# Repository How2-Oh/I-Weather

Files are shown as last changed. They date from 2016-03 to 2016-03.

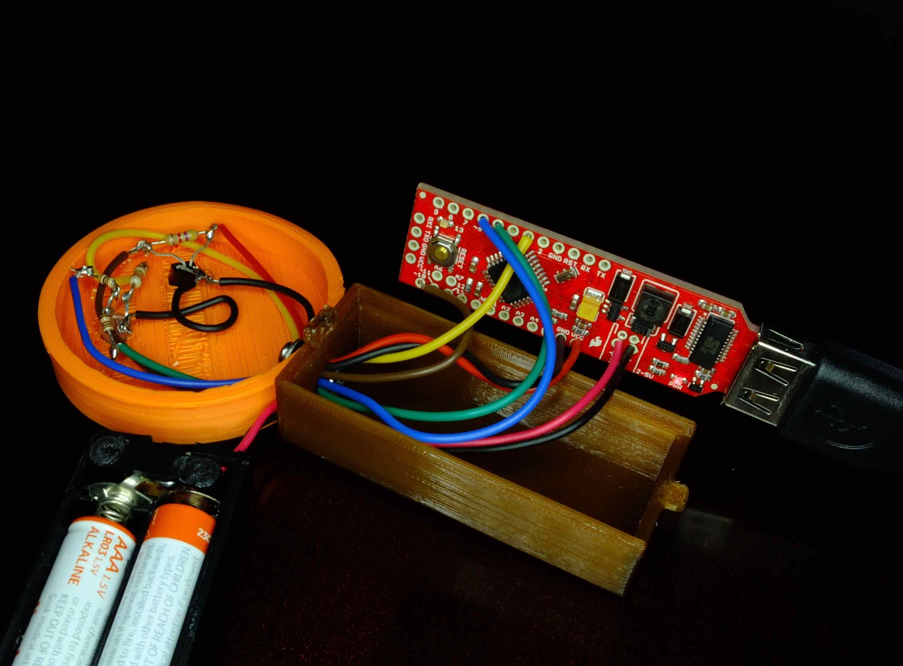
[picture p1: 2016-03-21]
Photos/Complete_Test.jpg

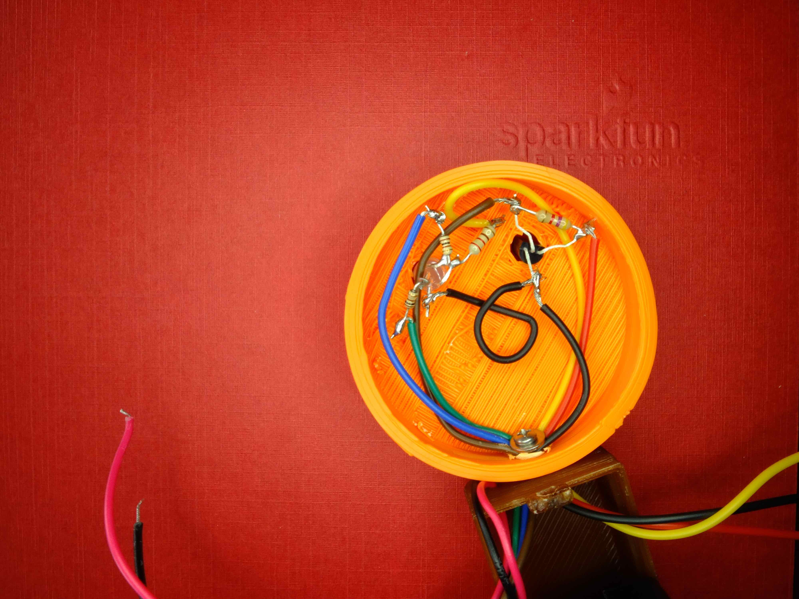
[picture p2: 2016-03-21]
Photos/Button_Wiring.jpg

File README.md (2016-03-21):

# I, Weather

Keep your "eye" on the weather. There are few areas in everyday life that suffer from data overload quite like the weather. All you want to know is, "what's it like outside right now?" Instead of a nice simple answer, you are deluged with more data points that you can sling a psychrometer at: dew points, inches of mercury (mercury!!), humidity, wind speed, and, of course, temperature. My kids don't want to know any of that "techie stuff," they just want to know is it "nice, hot, or cold" outside...right now.



Today with the SparkFun Electronics RedStick and a couple of discrete parts, you can answer that simple weather question with "I, Weather."

Securely installed inside a beautifully designed 3D-printed custom case (files available on Thingiverse), "I, Weather" provides you with a clear, easy-to-understand weather synopsis. Optimized Arduino code (files available on GitHub) featuring a WatchDog timer enables "I, Weather" to sip just enough juice from its dual AAA battery pack to keep your weather fix going and going.

Here's how it works: the RedStick is safely mounted inside the battery pack within a custom 3D-printed lid. The temperature sensor and RGB LED are neatly arranged inside a 3D-printed button disc. Two "eye" openings in the button enable the sensor to reliably read the ambient air temperature and the LED to "wink" the current temperature. A back is glued (use Testors Cement for Plastic Models No. 3512) on the button for protecting the internal wiring from dust and debris.

When the power switch is turned ON, "I, Weather" performs a startup test of the RGB LED, pulsing red, green, and blue. Upon completion of this test, the WatchDog timer kicks in and puts the RedStick to "sleep" for approximately 5 minutes. After the 5 minute interval, "I, Weather" wakes up, grabs a quick temperature reading, and pulses the RGB LED twice with the appropriate color: green = "nice;" 68 - 78 degs F, red = "hot;" above 78 degs F, and blue = "cold;" below 68 degs F. [Hey, we live on the Gulf Coast; and below 68 degs F IS kinda cool.]

##Parts

* SparkFun RedStick #DEV-13741
* LED - RGB Diffused Common Cathode #COM-09264
* One Wire Digital Temperature Sensor DS18B20 #SEN-00245
* Battery Holder 2xAAA with Cover and Switch #PRT-09543
* 4.7K, 180-ohm (I used a 220-ohm), (2) 100-ohm Resistor Kit #COM-10969
* Hook-Up Wire - Assortment #PRT-11375
* 2-56 Machine Screw Fastener, two 2-56 Washers, one 2-56 Hex Nut #PRT-08993, #PRT-08995

##Step-by-Step

1. Download, read, and understand ALL of the datasheets, schematics, and tutorials from SparkFun Electronics for each of the parts.

2. Solder the 180-ohm (or, 220-ohm) resistor to pin 1 of the RGB LED.

3. Solder the two 100-ohm resistors to pins 3 and 4 of the LED.

4. Solder the 4.7K resistor between pins 2 and 3 of the DS18B20. The remaining steps are simple wiring connections.

5. Attach a yellow wire (avoid a red wire so that you'll minimize confusion with the red "power" wires used later in this project) to the 180-ohm resistor on pin 1, a green wire to the 100-ohm resistor on pin 3, a blue wire to the final 100-ohm resistor on pin 4, and a black wire to pin 2 of the LED.

6. Solder a brown wire (or, white wire) to pin 2, a red wire to pin 3, and a black wire to pin 1 of the DS18B20 sensor.

7. Connect the black wire from the LED (see Step 5) to pin 1 of the sensor.

8. The wiring harness is now complete.

9. Mould the wiring, resistors, sensor, and LED so that they all fit comfortably inside the button disc. The sensor should sit flush with the outside of one of the button's eye openings, while the LED should protrude through the other eye opening.

10. Snake all wiring through the opening in the base of the button and through a matching opening inside the battery lid.

11. Run the external red and black wires from the battery pack through the two wire openings in the battery lid.

12. Secure the button to the battery lid with the 2-56 hardware.

13. Solder ALL wire connections to the RedStick: yellow (from pin 1 of the LED) to pin 3, green to pin 5, blue to pin 6, brown (from pin 2 of the sensor) to pin 10, red from the sensor to pin VCC, black from the sensor to pin GND, red from the battery pack to +, and black from the battery pack to -.

14. Connect the RedStick to your PC and upload the IWeather.ino code. [NOTE: I used a USB port extender cable connecting the RedStick to the PC.]

15. Ensure "I, Weather" is performing its startup sequence and pulsing the correct temperature every five minutes before you disconnect the PC.

16. If everything checks out OK, remove the RedStick from the PC and insulate the bottom of the board with a piece of tape (i.e., so the metal batteries don't short circuit any of the board's connections).

17. Glue the back on the button and stuff all of the wiring and RedStick inside the battery lid. [NOTE: there's a slot in the lid for enabling the RedStick's USB "fingers" to stick out.]

18. Insert two AAA batteries, slide the battery lid closed, secure the battery pack with a piece of tape, and install "I, Weather" inside/outside away from direct sunlight and moisture.

##Bonus "Expert" Tips

The red Power Indicator LED is continually drawing precious amounts of power from the battery pack. Carefully study the RedStick schematic and remove this LED (D2) along with the 6.8K resistor (R2).

If your "I, Weather" is constantly "resetting" itself during or following assembly, the RedStick "reset" button (S1) might be the culprit. Again, carefully review the RedStick schematic and remove this button.

-end-

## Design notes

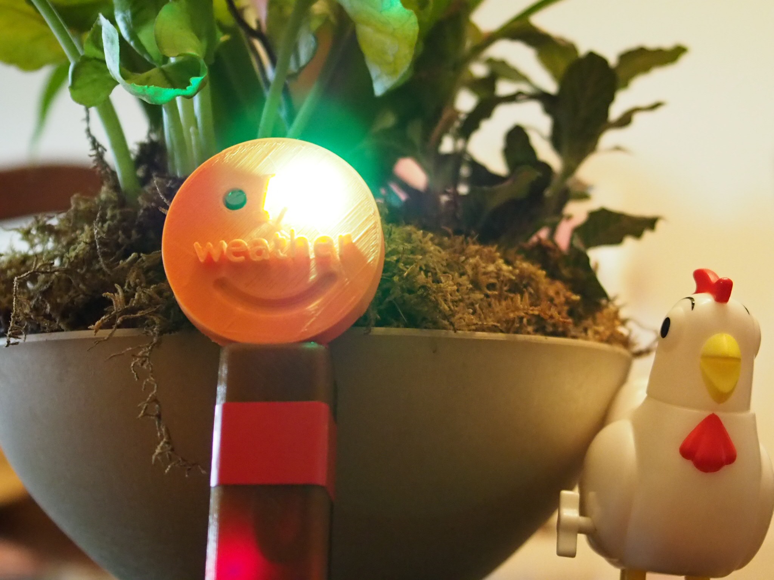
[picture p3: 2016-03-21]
Photos/Nice.JPG

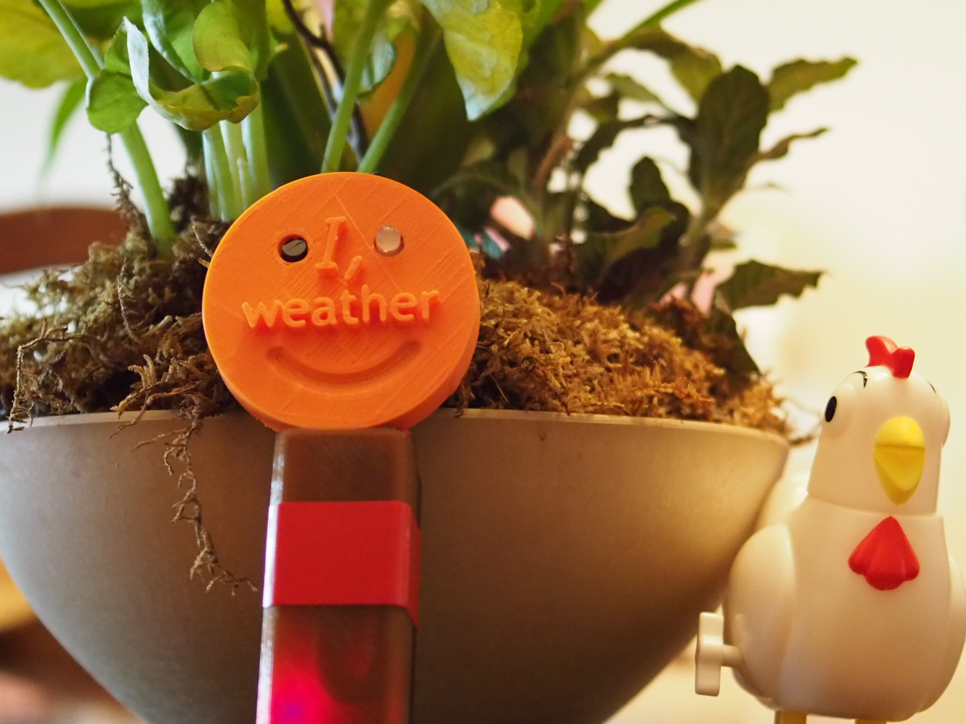
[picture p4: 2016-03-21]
Photos/IWeather.JPG

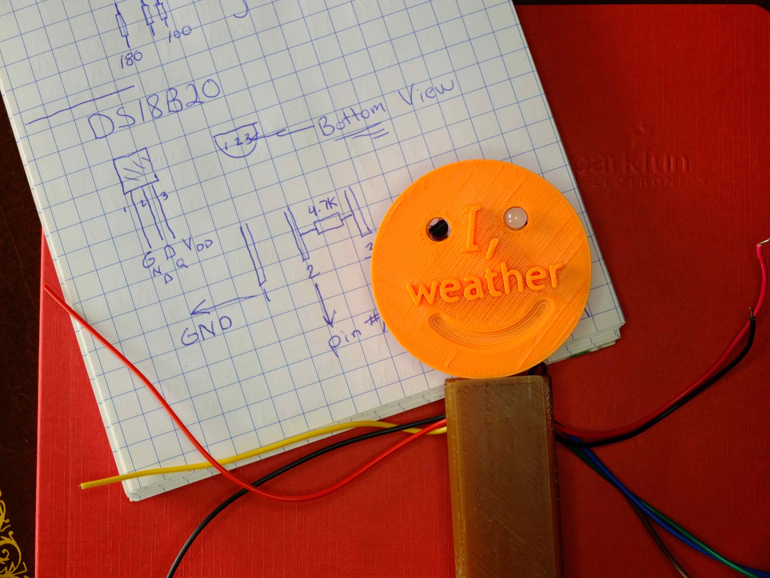
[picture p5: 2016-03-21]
Photos/Ready_4_RedStick.jpg

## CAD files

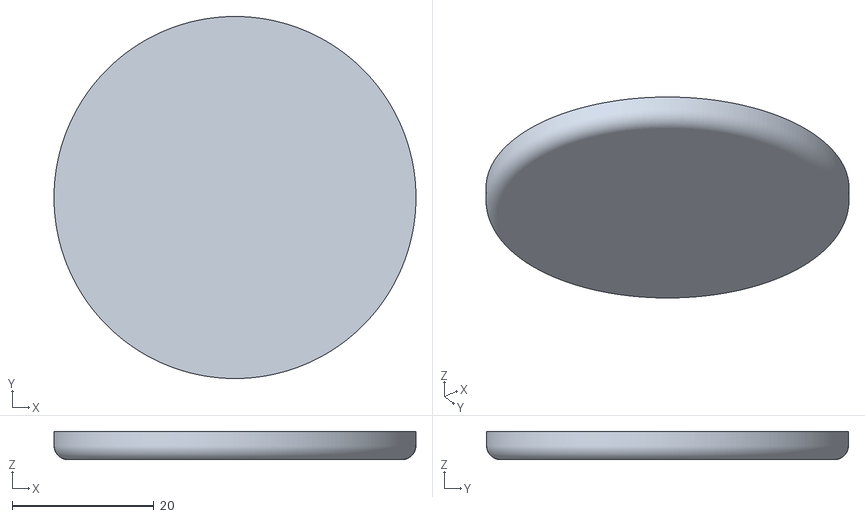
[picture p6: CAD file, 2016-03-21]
3DFiles/Weather_Back.stl
51.0 x 51.0 x 4.00

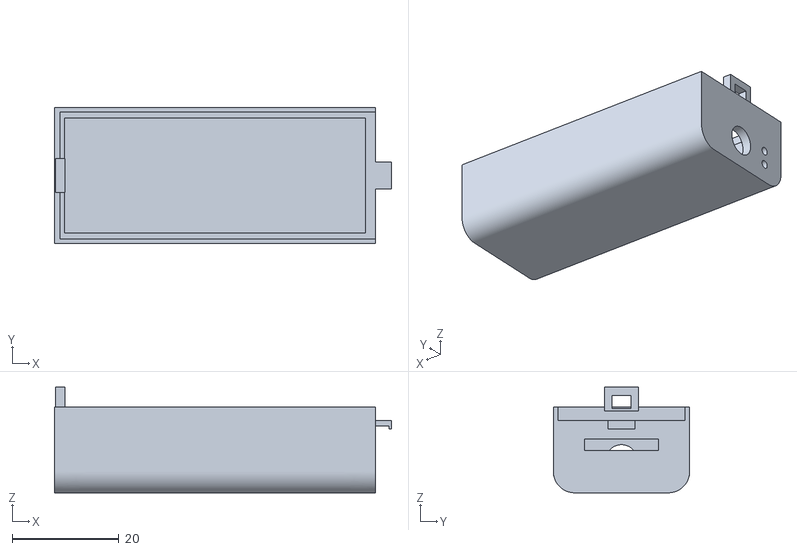
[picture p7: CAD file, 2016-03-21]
3DFiles/Battery_Lid.stl
63.0 x 25.5 x 19.8

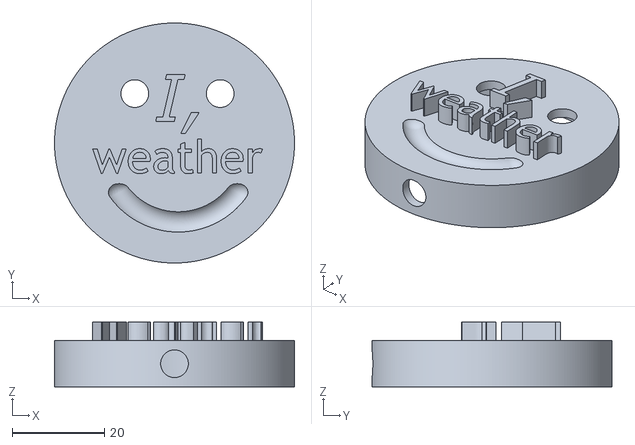
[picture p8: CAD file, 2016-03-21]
3DFiles/Weather_Button.stl
52.0 x 52.0 x 14.0

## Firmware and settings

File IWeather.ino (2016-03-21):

/* I, Weather
 *  A SparkFun Electronics RedStick Companion
 *  
 *  Based on the following libraries:
  * OneWire DS18B20 Thermometer
 *
 * RGB LED by BARRAGAN http://barraganstudio.com
 * 
 * The Watchdog & Sleep Mode code was lovingly adapted from
   Nathan Seidle's SparkFun Electronics Arduino code for
   H2OhNo!.


This sketch enables you to read a temperature from the  
connected DS18B20 and display the results on an PWM-
connected RGB LED.

RGB LED:
RedStick -------------------------------- RGB LED
3 -------------- 180-ohm resistor ------- 1 (Red)
5 -------------- 100-ohm resistor ------- 3 (Green)
6 -------------- 100-ohm resistor ------- 4 (Blue)
GND ------------------------------------- 2 (Common Cathode)

DS18B20:
RedStick --------------- DS18B20
VCC -------------------- VDD (pin #3)
10 --------------------- DQ (pin #2)
GND -------------------- GND (pin #1)
5V --- 4.7K resistor --- DQ (pin #2)

2xAAA Battery Pack:
RedStick ----------- Battery Pack
+ ------------------ Battery Red
- ------------------ Battery Black
*/

#include <OneWire.h>
#include <avr/sleep.h>

int i = 0; // An incremental timing variable for use during display

// Variables for the RGB LED
int RedPin = 3; //RED pin of the LED to PWM pin 3
int GreenPin = 5; // GREEN pin of the LED to PWM pin 5
int BluePin = 6; // BLUE pin of the LED to PWM pin 6
int brightness = 0; // LED brightness
int increment = 5; // brightness increment

// Our DS18B20 temperature variables
float celsius, fahrenheit;

OneWire  ds(10);  // Thermometer is on pin 10 (a 4.7K resistor is necessary)

volatile int watchdog_counter;

//This runs each time the watchdog wakes up
ISR(WDT_vect){
  watchdog_counter++;
}

void setup()
{

// Configure the RGB LED for OUTPUT
  pinMode(RedPin, OUTPUT);
  pinMode(GreenPin, OUTPUT);
  pinMode(BluePin, OUTPUT);

// Countdown to start R -> G -> B
  for (i=0; i<100; i++) {
    brightness = brightness + increment;  // increment brightness for next loop iteration
      if (brightness <= 0 || brightness >= 255)
        {
          increment = -increment;
        }
    brightness = constrain (brightness, 0, 255);
    analogWrite(RedPin, brightness);
// reverse the direction of the fading
    delay(20); // wait for 20 milliseconds to see the dimming effect
  }
  for (i=0; i<100; i++) {
    brightness = brightness + increment;  // increment brightness for next loop iteration
      if (brightness <= 0 || brightness >= 255)
        {
          increment = -increment;
        }
    brightness = constrain (brightness, 0, 255);
    analogWrite(GreenPin, brightness);
// reverse the direction of the fading
    delay(20); // wait for 20 milliseconds to see the dimming effect
  }
  for (i=0; i<100; i++) {
    brightness = brightness + increment;  // increment brightness for next loop iteration
      if (brightness <= 0 || brightness >= 255)
        {
          increment = -increment;
        }
    brightness = constrain (brightness, 0, 255);
    analogWrite(BluePin, brightness);
// reverse the direction of the fading
    delay(20); // wait for 20 milliseconds to see the dimming effect
  }
// Turn LED OFF
  brightness = 0;
  analogWrite(BluePin, brightness);
  analogWrite(RedPin, brightness);
  analogWrite(GreenPin, brightness);

// Our sleep code
watchdog_counter = 0;

//Power down all unnecessary hardware
set_sleep_mode(SLEEP_MODE_PWR_DOWN);
sleep_enable();
ADCSRA &= ~(1<<ADEN); //Disables the ADC

setup_watchdog(7); //Wake up after 2 sec
}

void loop() 
{
  sleep_mode(); //Go to sleep for approximately 300 sec = 5 min

  if(watchdog_counter > 150) {
    watchdog_counter = 0;

// Get the temperature
  updateTemp();

// According to human preferences, the ideal comfort temperature level = 68-78 degrees F
// Therefore, Green = Ideal Temperature
// Red = Hot Temperature
// Blue = Cold Temperature

  if (fahrenheit >= 68 && fahrenheit <= 78) {
      for (i=0; i<200; i++) {
    brightness = brightness + increment;  // increment brightness for next loop iteration
      if (brightness <= 0 || brightness >= 255)
        {
          increment = -increment;
        }
    brightness = constrain (brightness, 0, 255);
    analogWrite(GreenPin, brightness);
// reverse the direction of the fading
    delay(20); // wait for 20 milliseconds to see the dimming effect
  }
  // Now turn OFF LED
  brightness = 0;
  analogWrite(GreenPin, brightness);
  }

// Temperature above 78 is HOT
  if (fahrenheit > 78) {
      for (i=0; i<200; i++) {
    brightness = brightness + increment;  // increment brightness for next loop iteration
      if (brightness <= 0 || brightness >= 255)
        {
          increment = -increment;
        }
    brightness = constrain (brightness, 0, 255);
    analogWrite(RedPin, brightness);
// reverse the direction of the fading
    delay(20); // wait for 20 milliseconds to see the dimming effect
  }
  // Now turn OFF LED
  brightness = 0;
  analogWrite(RedPin, brightness);
  }
  
// Temperature below 68 is COLD
  if (fahrenheit < 68) {
      for (i=0; i<200; i++) {
    brightness = brightness + increment;  // increment brightness for next loop iteration
      if (brightness <= 0 || brightness >= 255)
        {
          increment = -increment;
        }
    brightness = constrain (brightness, 0, 255);
    analogWrite(BluePin, brightness);
// reverse the direction of the fading
    delay(20); // wait for 20 milliseconds to see the dimming effect
  }
  // Now turn OFF LED
  brightness = 0;
  analogWrite(BluePin, brightness);
  }
  }
}

// Grab the temperature from the sensor and determine the degrees in F
void updateTemp()
{
  byte j;
  byte present = 0;
  byte type_s;
  byte data[12];
  byte addr[8];
  //float celsius, fahrenheit;
  
  if ( !ds.search(addr)) {
    ds.reset_search();
    delay(250);
    return;
  }
  
  for( j = 0; j < 8; j++) {
  }

  if (OneWire::crc8(addr, 7) != addr[7]) {
      return;
  }
 
  // the first ROM byte indicates which chip
  switch (addr[0]) {
    case 0x10:
      //Serial.println("  Chip = DS18S20");  // or old DS1820
      type_s = 1;
      break;
    case 0x28:
      //Serial.println("  Chip = DS18B20");
      type_s = 0;
      break;
    case 0x22:
      //Serial.println("  Chip = DS1822");
      type_s = 0;
      break;
    default:
      //Serial.println("Device is not a DS18x20 family device.");
      return;
  } 

  ds.reset();
  ds.select(addr);
  ds.write(0x44, 1);        // start conversion, with parasite power on at the end
  
  delay(1000);     // maybe 750ms is enough, maybe not
  // we might do a ds.depower() here, but the reset will take care of it.
  
  present = ds.reset();
  ds.select(addr);    
  ds.write(0xBE);         // Read Scratchpad

  for ( j = 0; j < 9; j++) {           // we need 9 bytes
    data[j] = ds.read();
  }

  // Convert the data to actual temperature
  // because the result is a 16 bit signed integer, it should
  // be stored to an "int16_t" type, which is always 16 bits
  // even when compiled on a 32 bit processor.
  int16_t raw = (data[1] << 8) | data[0];
  if (type_s) {
    raw = raw << 3; // 9 bit resolution default
    if (data[7] == 0x10) {
      // "count remain" gives full 12 bit resolution
      raw = (raw & 0xFFF0) + 12 - data[6];
    }
  } else {
    byte cfg = (data[4] & 0x60);
    // at lower res, the low bits are undefined, so let's zero them
    if (cfg == 0x00) raw = raw & ~7;  // 9 bit resolution, 93.75 ms
    else if (cfg == 0x20) raw = raw & ~3; // 10 bit res, 187.5 ms
    else if (cfg == 0x40) raw = raw & ~1; // 11 bit res, 375 ms
    //// default is 12 bit resolution, 750 ms conversion time
  }

  celsius = (float)raw / 16.0;
  fahrenheit = celsius * 1.8 + 32.0;
}

void setup_watchdog(int timerPrescaler) {

  if(timerPrescaler > 9) timerPrescaler = 9; //Adjust amount

  byte bb = timerPrescaler & 7;
  if (timerPrescaler > 7) bb |= (1<<5); //Set 5th bit if needed

  // This sequence can NOT be altered
  MCUSR &= ~(1<<WDRF); //Clear the watchdog reset
  WDTCSR |= (1<<WDCE) | (1<<WDE); //Set WD_change & WD both enable
  WDTCSR = bb; //Set new watchdog timeout
  WDTCSR |= _BV(WDIE); //Set interrupt enable
}
